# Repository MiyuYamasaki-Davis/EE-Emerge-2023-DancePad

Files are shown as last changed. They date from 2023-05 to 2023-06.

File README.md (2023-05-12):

# Dance Pad Maze Game

[Dance Pad Maze Game](https://github.com/EE-Emerge/EE-Emerge-2023-DancePad) is a game project created by a team of UC Davis [EE-Emerge](https://www.ece.ucdavis.edu/ieee/home/ee-emerge/) (EEC 105ABC) students. This project allows a user to play a game in which they must navigate a maze by using a 4-directional pressure pad controller we built ourselves.

## Table of Contents

1. [About the Project](#about-the-project)
2. [Project Status](#project-status)
3. [Getting Started](#getting-started)
    1. [Dependencies](#dependencies)
    1. [Building](#building)
4. [How to Get Help](#how-to-get-help)
5. [Further Reading](#further-reading)
6. [Authors](#authors)
7. [Acknowledgements](#acknowledgements)

# About the Project

Maze Game, inspired by the popular arcade game Dance Dance Revolution, or commonly abbreviated as DDR, is an interactive game that challenges the user to think on the fly and tests their cognitive capabilities. The basic premise of the game is to navigate randomized mazes with the use of four pressure pads, indicating the direction of which the user can move: forward, back, left and right. The user simply has 30 seconds to complete as many mazes as they can and can compete their skills against other friends and competitors for a spot on the record leaderboard.

# Project Status

Modifications to Pressure Plates
Restructuring of Enclosure
Redesign of PCB

# Getting Started

This repository can be downloaded [here](https://github.com/EE-Emerge/EE-Emerge-2023-DancePad/archive/master.zip), or cloned by:
```
git clone https://github.com/EE-Emerge/EE-Emerge-2023-DancePad
```

## Dependencies

#### Software
[Visual Studio](https://visualstudio.microsoft.com/vs/) was our main program we used to run the game and algorithm.

[Arduino IDE](https://www.arduino.cc/en/software) was used to be able to facilitate communicate between our circuit and the computer.

#### Hardware & Model Creation
[Altium](https://www.altium.com/) was used for most PCB creation.  
[Fusion 360](https://www.autodesk.com/products/fusion-360/overview) was used for the creation of enclosures and other mechanical files.  

## Building

PCB and enclosure files will be located in respective subdirectories. These were fabricated either with a 3D printer, a laser cutter, or table saw.

Software will have to be compiled and loaded into Visual Studio 2022 and Arduino IDE respectively.

# How to Get Help

You can request any changes by making a [pull request](https://github.com/EE-Emerge/EE-Emerge-2023-DancePad/pulls) or opening an issue.

# Further Reading

* [MST Algorithm](https://www.geeksforgeeks.org/kruskals-minimum-spanning-tree-algorithm-greedy-algo-2/)

# Authors

* [Grant Yamaguchi](https://github.com/MiyuYamasaki-Davis)
* [Liana Goldstein](https://)
* [Ricky](https://)
* [RJ](https://)
* [Rameen](https://)
* [Gabe](https://)
* [Cesar Luna](https://)
* [Rayyan](https://)
* [Sean Alling](https://www.ece.ucdavis.edu/blog/alling-sean/)
* [Professor Andre Knoesen](https://faculty.engineering.ucdavis.edu/knoesen/)

# Acknowledgments

Thanks to Texas Instruments for sponsoring EE-Emerge, along with Sean Alling and Dr. Andre Knoesen. We would not have gotten this far without their help and support.

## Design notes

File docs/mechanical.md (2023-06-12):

# Encasement and Mechanical Design

The directional pad encasement is made out of wood and acrylic to minimize cost and create more durability in the frame to allow for all player sizes (children, adults, etc.). The board is was designed in Fusion 360 and custom-made by the team, with areas for wires to go between sections, output to a computer outside the board, and allow for proper compresion of each arrow plate.

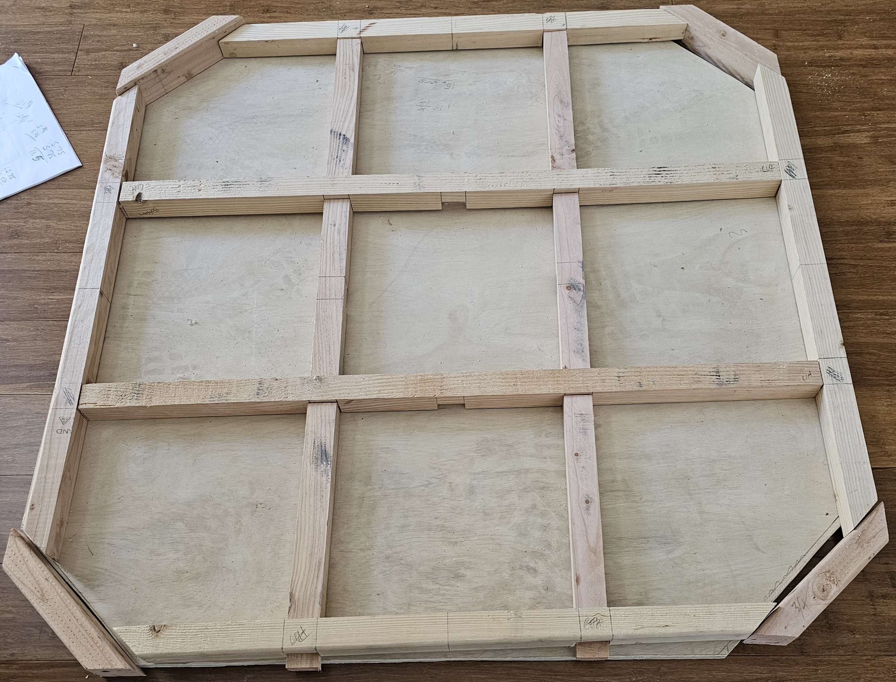
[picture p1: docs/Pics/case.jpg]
Encasement


The PCBs and microcontroller are protected in the center square and receive inputs from each arrow square. Each arrow square contains two wood pieces with copper tape that face each other on opposing sides (top and bottom), which are connected to a designated comparator circuit in our PCB via soldered wires. The two wood pieces are separated by foam pieces placed in corners of the square, preventing contact between the copper tapes when the arrow is unpressed, and creating an open circuit. When the arrow is pressed, the foam compresses and the wood flexes, allowing contact between the copper tapes, changing the circuit from an open circuit to a closed circuit, and signaling to the comparator circuit that an arrow has been pressed.

The system we use in conjunction with the comparator circuit is a pressure plate-like mechanism. 

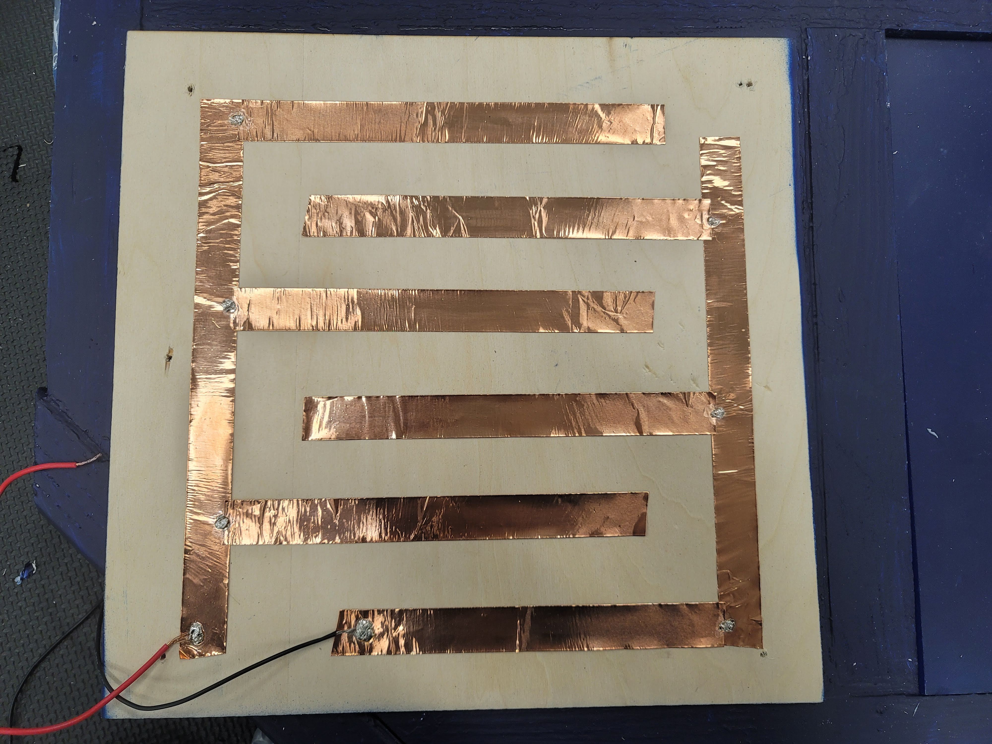
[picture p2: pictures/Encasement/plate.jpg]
Plate Design PHOTO


By layering copper conductive tape and connecting the wires on the bottom plate as shown above, and using no wires and diagonally placed copper tape on the top plate, there is a large area that the player can step on in order to complete the circuit. The top plate tape acts as a jumper between the positive and negative connections of the tape on the bottom plate. This triggers the comparator circuit to allow a voltage through the operational amplifier, creating an analog signal to be converted by the arduino, which then communicates with our C++ game, allowing the user to play.

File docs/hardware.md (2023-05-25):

# Hardware Design

Our PCB's purpose is to compare two voltages. A threshold voltage and the pressure plate voltage. Once the pressure plate is pressed it becomes higher than the threshold. Therefore registering a press on our sensor. We accomplished this by using a comparator circuit.

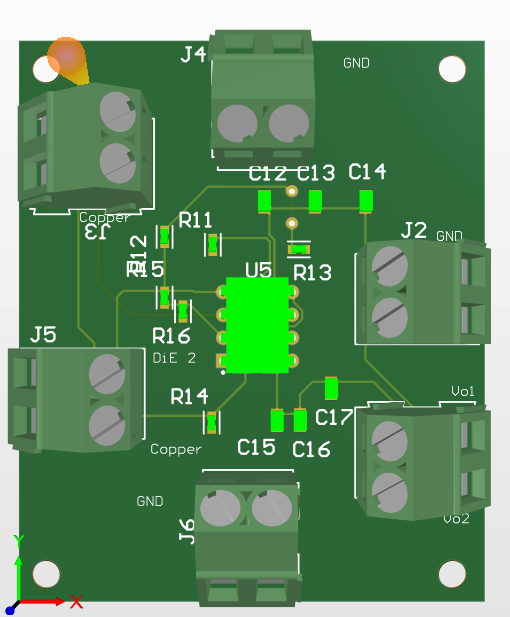
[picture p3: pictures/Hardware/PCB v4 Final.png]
Comparator


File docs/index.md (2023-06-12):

# Pressure Plate Maze Game

[Pressure Plate Maze Game](https://github.com/EE-Emerge/EE-Emerge-2023-DancePad) is a game project created by a team of UC Davis [EE-Emerge](https://www.ece.ucdavis.edu/ieee/home/ee-emerge/) (EEC 105ABC) students. The Maze Game, inspired by the popular arcade game Dance Dance Revolution, is an interactive game that challenges the user to think on the fly and test their cognitive capabilities. The premise of the game is to navigate through randomized mazes using four pressure pads indicating the direction the user will move: forward, back, left and right. The user simply has 30 seconds to complete as many mazes as they can, attempting to beat their friends and competitors and gain a spot on the leaderboard.

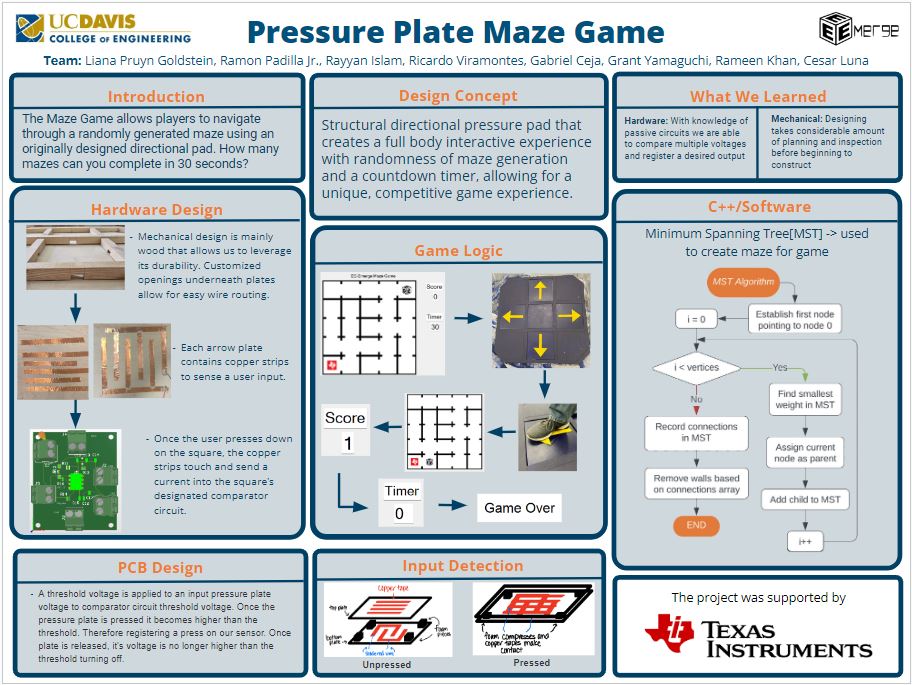
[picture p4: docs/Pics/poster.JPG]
Poster


# About the Project

Pressure Plate Maze Game is a project developed during the 2022/2023 academic year by the undergraduates from EE-Emerge, a project based class at the University of California Davis, designed for students in Computer and Electrical Engineering students to utilize their engineering knowledge and collaborate with others to create a project based on a a yearly theme. In 2022/2023, the students were tasked with creating something to inspire K-12 students and get them interested in Engineering. The Maze Game is an interactive game where the user is challenged to navigate through as many mazes as they can with the use of a 4 direction pressure pad. The user can either move forward, back, left and right and has to complete as many mazes possible in the allocated 30 seconds. At the core of the Maze Game’s technology, inside the middle plate of the pressure pad housing, there are custom PCBs which the team designed and fabricated. The housing has also been designed, laser cut, built, and painted by the team. The PCBs are connected directly with each pad and have a basic function of detecting when the pad is pressed by reading the voltage from our mechanism, which will be either an open or short circuit based on the pressure applied (open when unpressed and short when pressed). The mechanism is connected through the PCBs and microcontroller, where the analog data is looped and debounced, and sent through the serial port to the computer. The randomized mazes and computer game as a whole were created in C++ and utilize minimum spanning trees to generate randomized mazes with a minimum of 3 spaces in between the users starting point and the designated end point.

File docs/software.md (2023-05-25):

# Software Design
The project incorporates a randomly generated maze as the game through an algorithm known as a Minimum Spanning Tree, or MST. This algorithm utilizes randomly assigned weights between neighboring nodes, then runs a procedure to connect the nodes based on the smallest weights found. From this, the program is able to create a tree with dangling child nodes that result in dead ends. This solution also guarantees that a single path from any one point to another will always be feasible, no matter the points chosen.

This project was handled by two software programs: Visual Studio 2022 Community Build and Arduino IDE

## Visual Studio 2022
Visual Studio 2022 is an open source IDE that allows utilization of C++/CLI to develop graphics based C++ projects. It was chosen as the optimal coding environment for C++.

## Arduino IDE
Arduino IDE is the coding source for the Arduino Uno board used to fascilitate Analog-to-Digital Conversion for communication between the PCB and computer.

## Minimium Spanning Tree Algorithm Flowchart
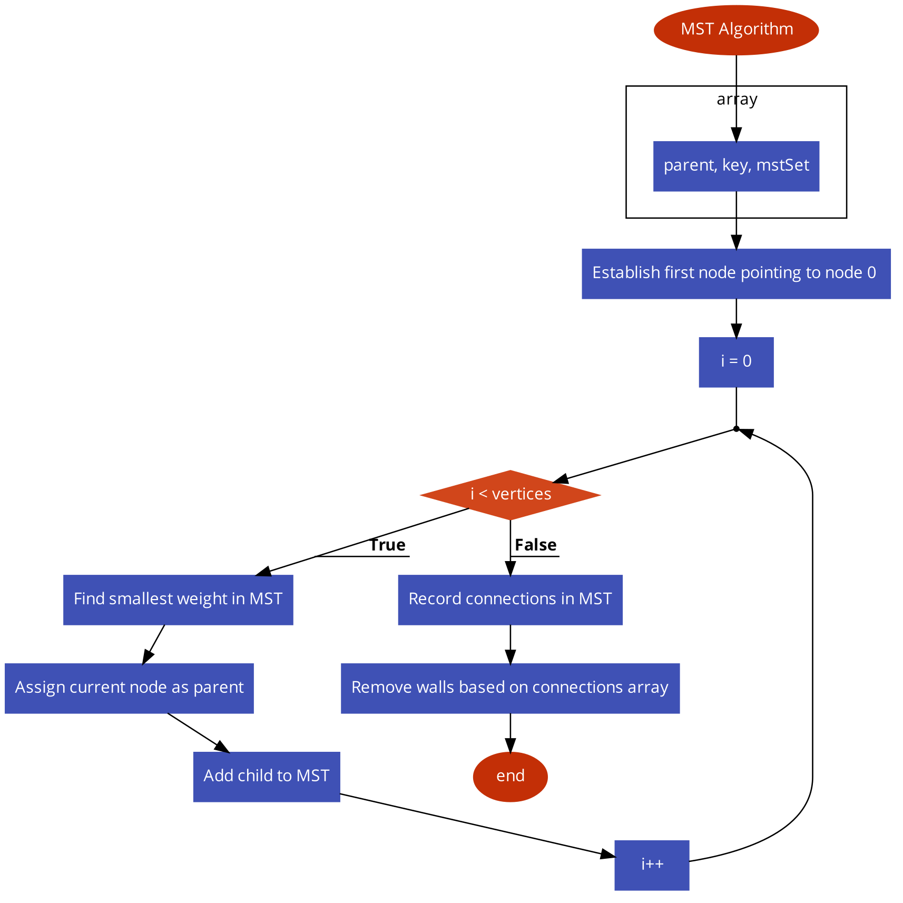
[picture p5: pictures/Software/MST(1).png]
MST


## Timer Loop Flowchart
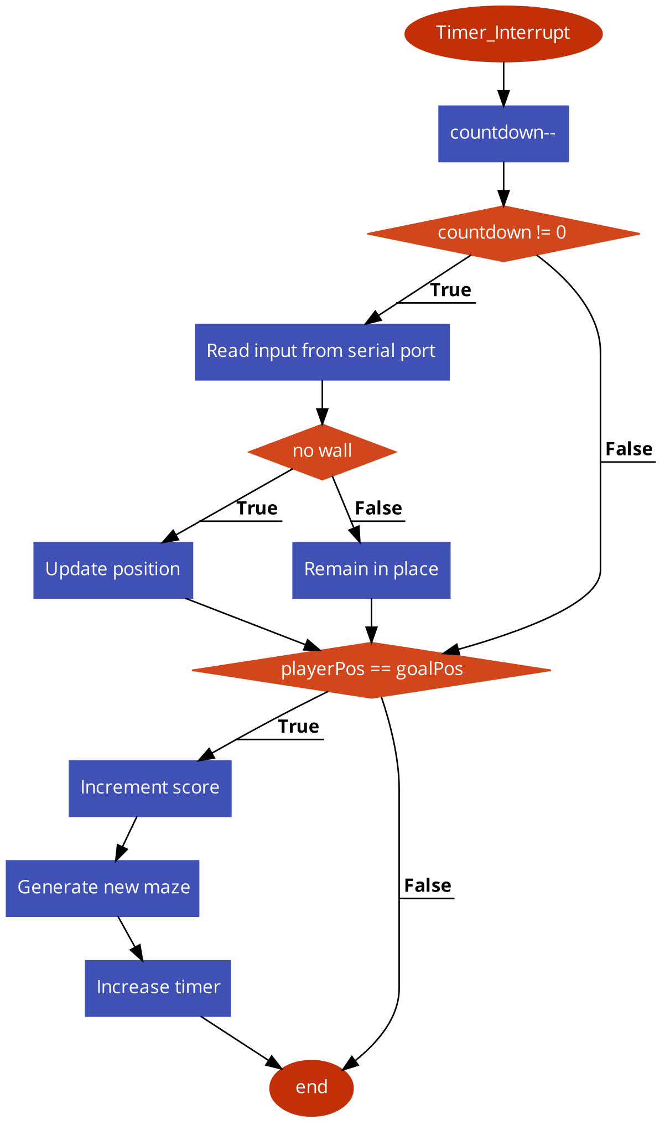
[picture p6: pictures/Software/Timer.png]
Timer


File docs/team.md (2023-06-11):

# Team



| | |
|:---:|:---:|
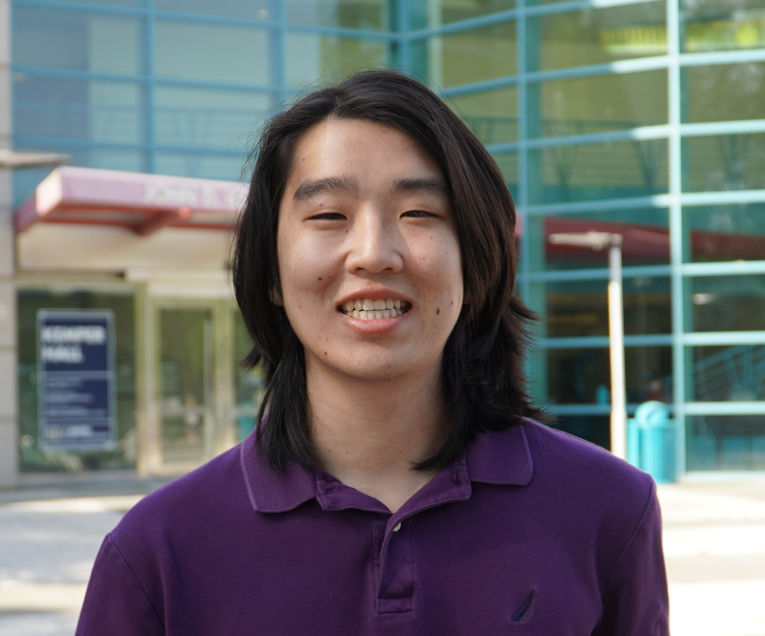
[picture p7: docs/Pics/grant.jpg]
|**Grant Yamaguchi** <br/> **Team Leader / Lead Programmer** <br/> B.S. Computer Engineering 2025 <br/> Major Focus: C++, Python <br/> [LinkedIn](www.linkedin.com/in/grant-j-m-yamaguchi) & [GitHub](https://github.com/MiyuYamasaki-Davis) |  | 
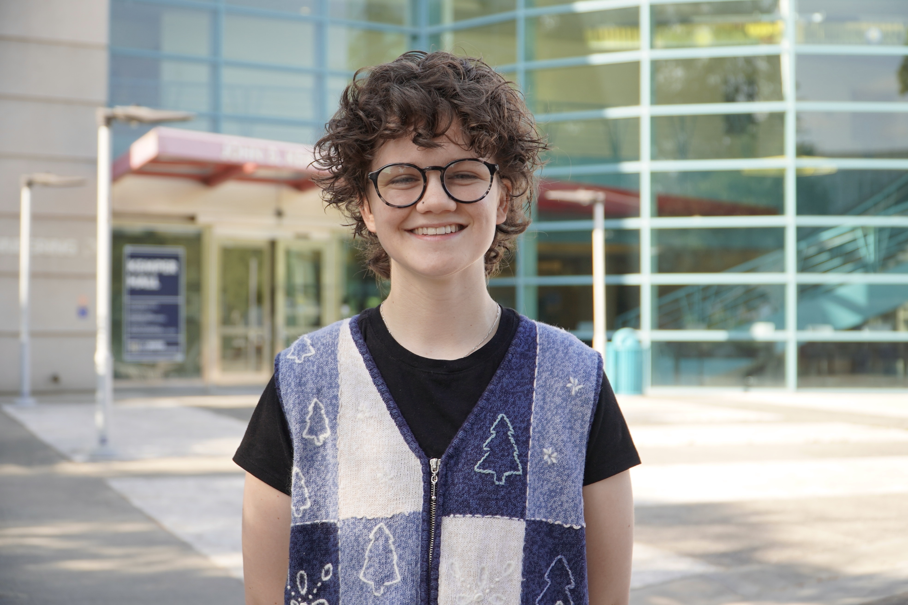
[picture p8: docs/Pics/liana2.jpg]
|**Liana Pruyn Goldstein** <br/> **Team Leader / Various Roles** <br/> B.S. Computer Engineering 2025 <br/> Major Focus: N/A <br/> [LinkedIn](https://www.linkedin.com/in/liana-pruyn-goldstein-94a753207/) |  |
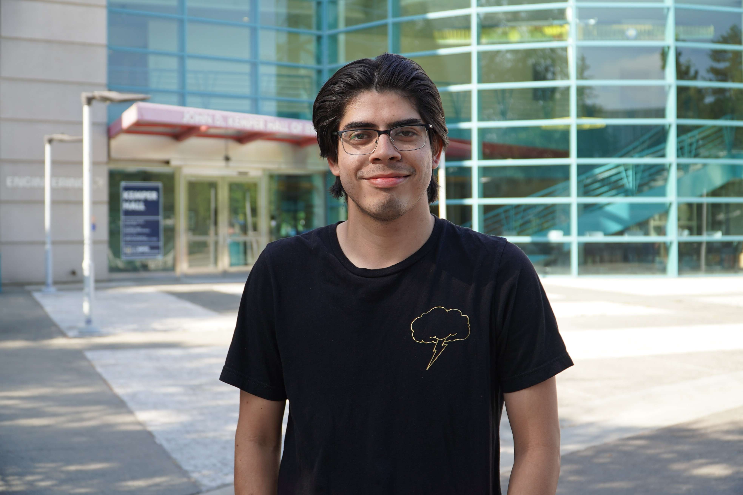
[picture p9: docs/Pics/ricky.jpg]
|**Ricardo Viramontes** <br/> **Hardware Design** <br/> B.S. Electrical Engineering 2024 <br/> Major Focus: RFIC Design <br/> |  |
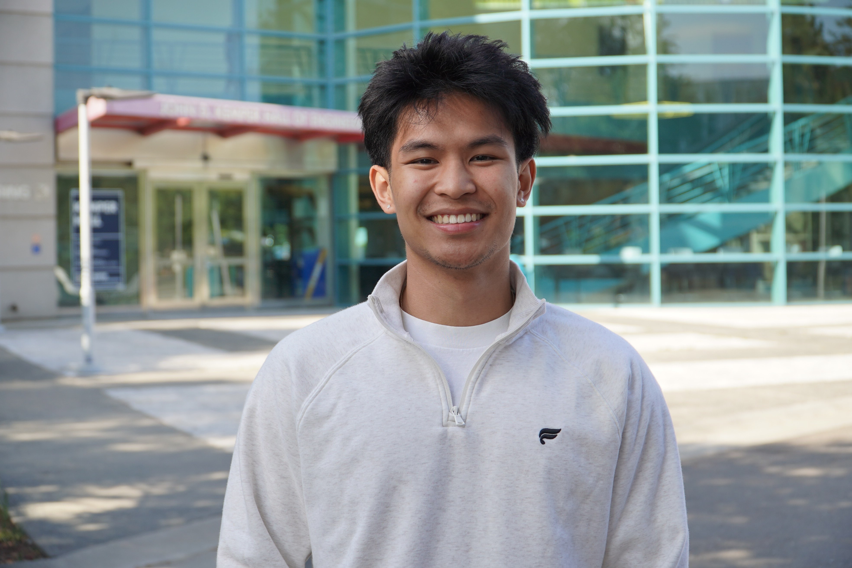
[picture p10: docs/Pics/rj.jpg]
|**Ramon Lamamigo Padilla Jr.** <br/> **Hardware Assembly** <br/> B.S. Electrical Engineering 2024 <br/> Major Focus: RF/Electromagnetics <br/> [LinkedIn](https://www.linkedin.com/in/rj-padilla-9519b3199/) & [GitHub](https://github.com/rjpadilla) |  |
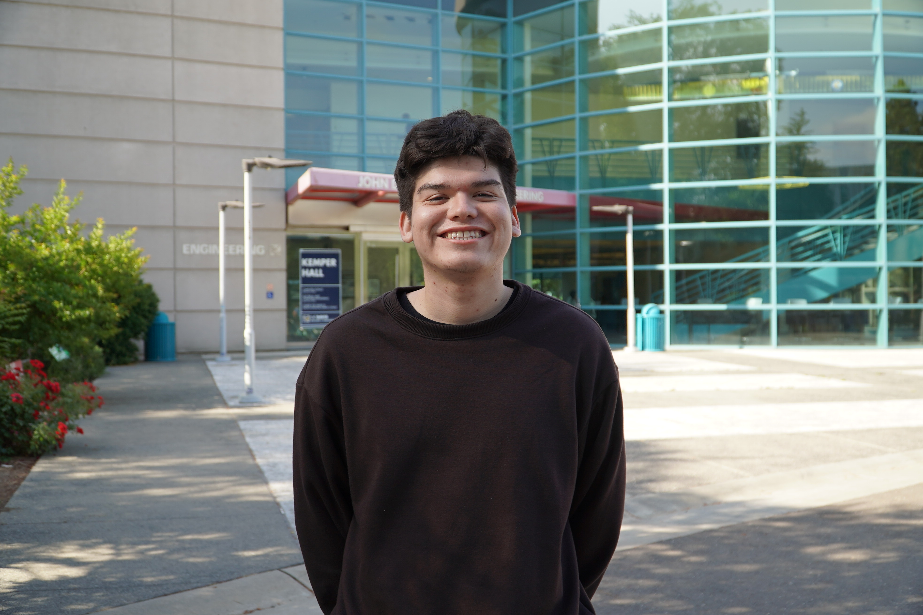
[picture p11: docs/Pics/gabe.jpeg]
|**Gabriel Ceja** <br/> **Encasement & Hardware Design** <br/> B.S. Electrical Engineering 2024 <br/> Major Focus: Analog Design <br/> [LinkedIn](www.linkedin.com/in/gabrielceja) & [GitHub](https://github.com/gabrielceja) |  |
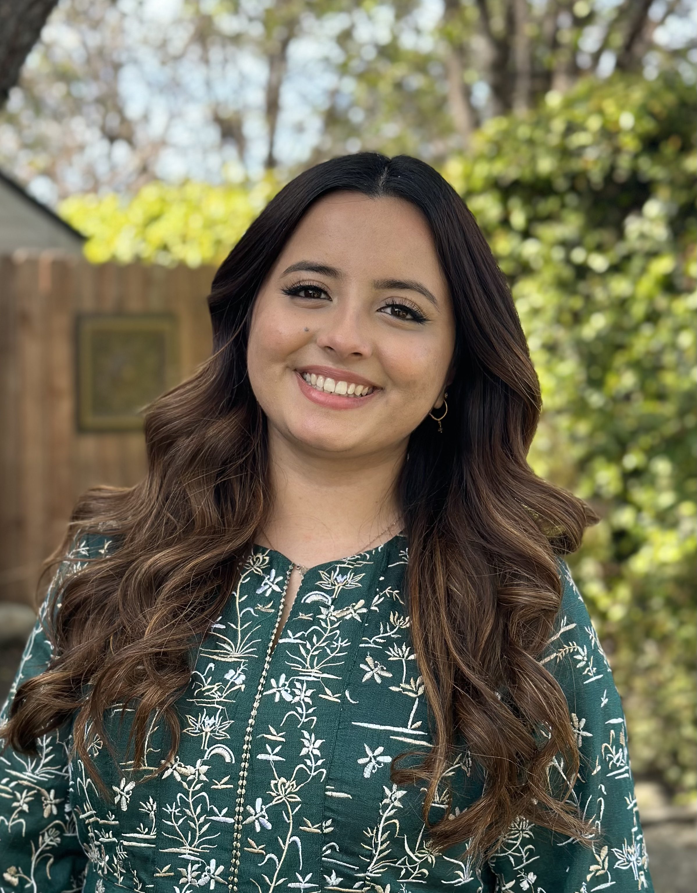
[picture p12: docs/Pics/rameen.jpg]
|**Rameen Khan** <br/> **Encasement & Hardware Design** <br/> B.S. Electrical Engineering 2024 <br/> Major Focus: N/A <br/> [LinkedIn](https://www.linkedin.com/in/rameen-a-khan) & [GitHub](https://github.com/rameeeeenkhan) |  |
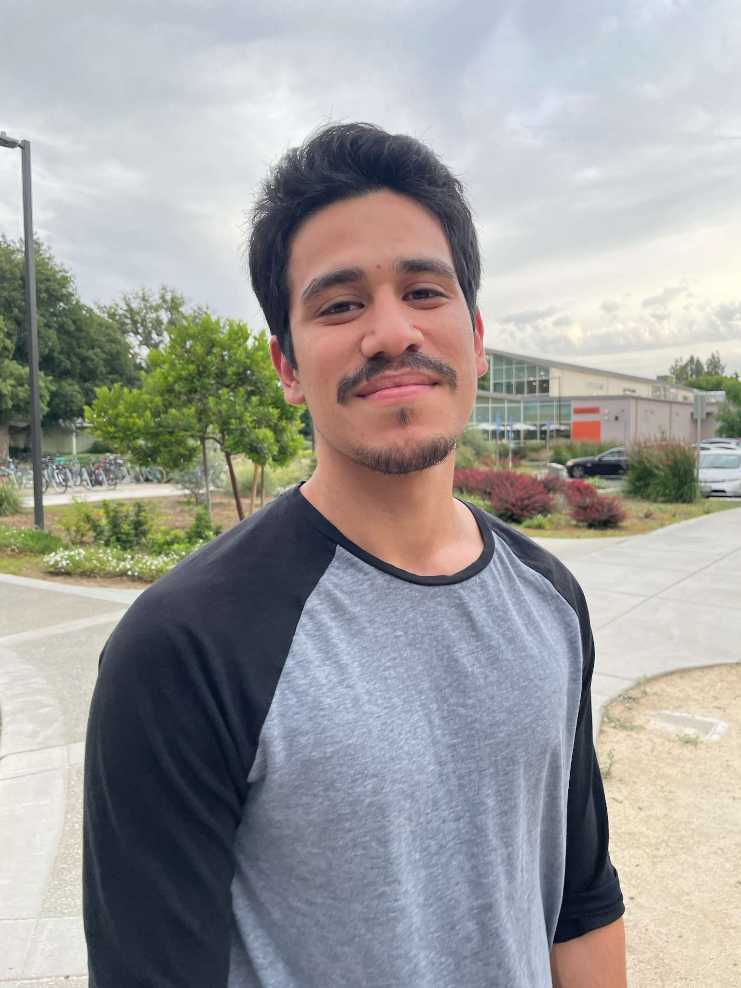
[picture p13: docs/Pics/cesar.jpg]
|**Cesar Luna** <br/> **Various Roles** <br/> B.S. Electrical Engineering 2024 <br/> Major Focus: N/A <br/> [LinkedIn](https://www.linkedin.com/in/cesar-luna-321a45222) & [GitHub](https://github.com/Cesar-A-Luna) |  |
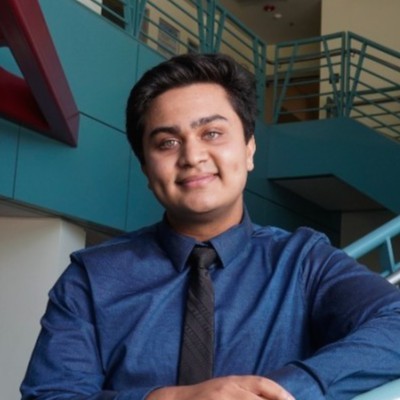
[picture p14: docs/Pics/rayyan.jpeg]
|**Rayyan Islam** <br/> **Various Roles** <br/> B.S. Electrical Engineering 2024 <br/> Major Focus: RF Design <br/> [LinkedIn](https://www.linkedin.com/in/rayyislam/) |  |

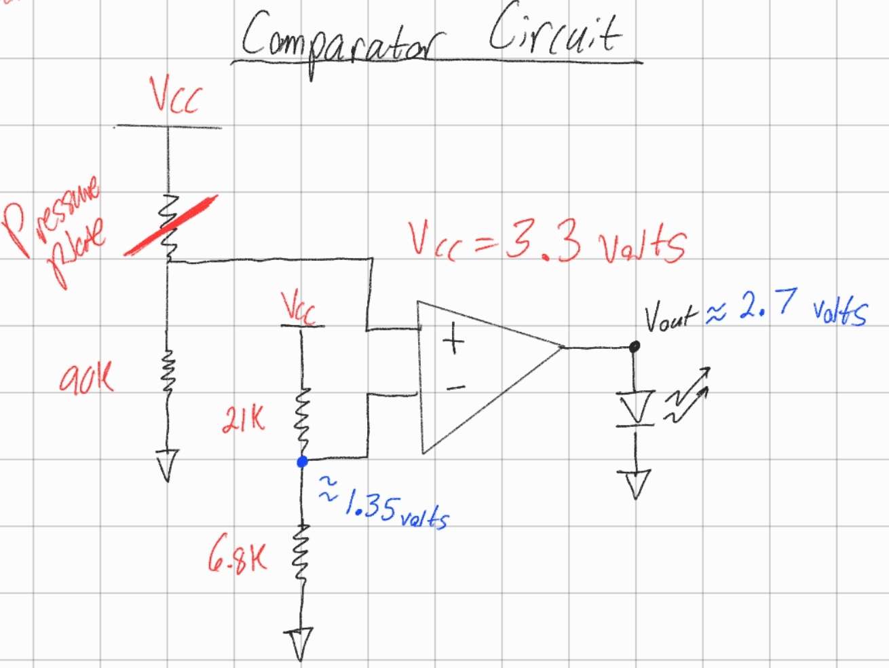
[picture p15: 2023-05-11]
pictures/Hardware/Comparator design.jpg

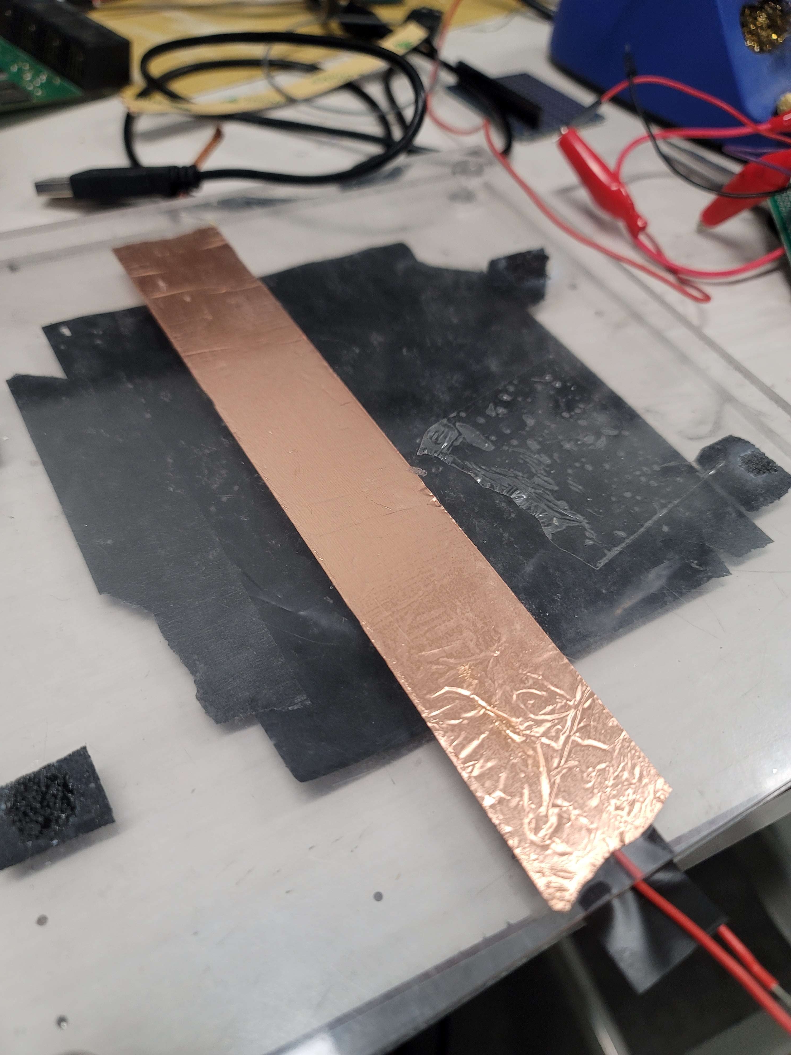
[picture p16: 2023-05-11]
pictures/Encasement/v4 plate design.jpg

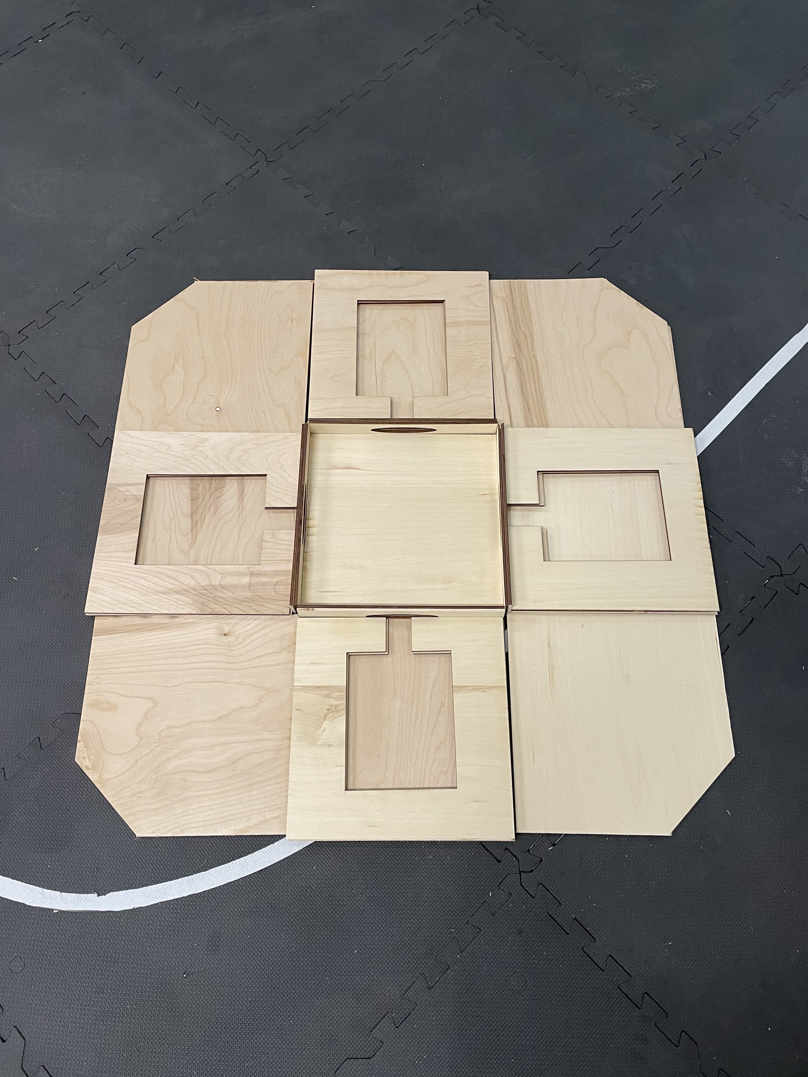
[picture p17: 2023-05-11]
pictures/Encasement/v3 platform design.jpg

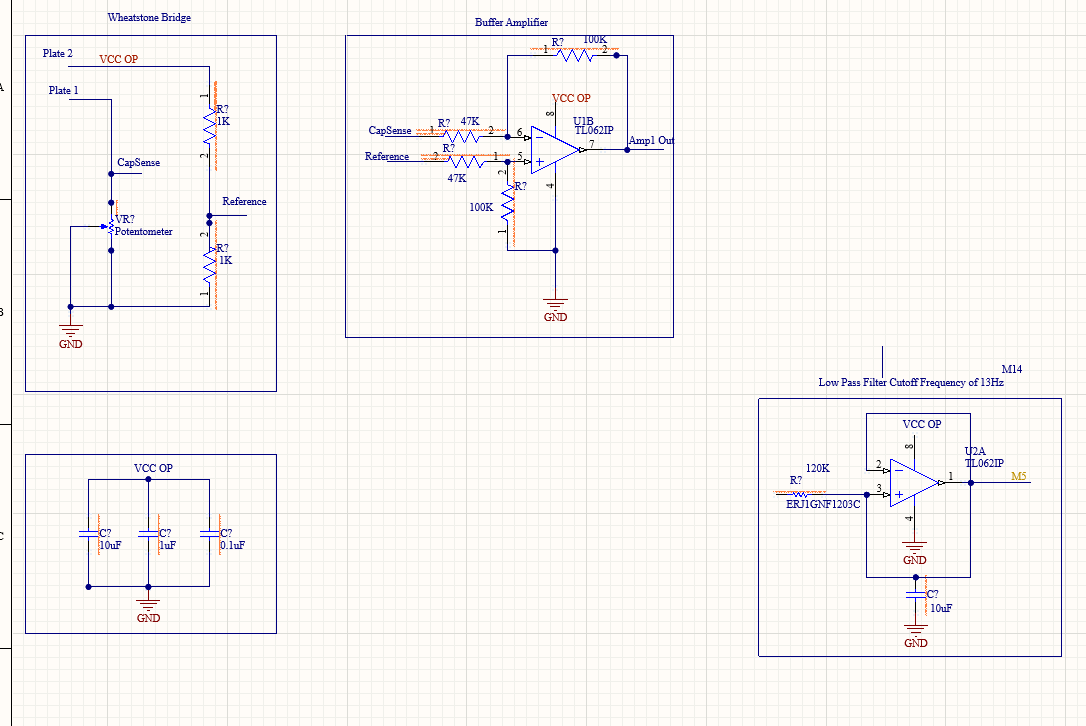
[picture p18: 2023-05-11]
pictures/Hardware/v2 PCB.png

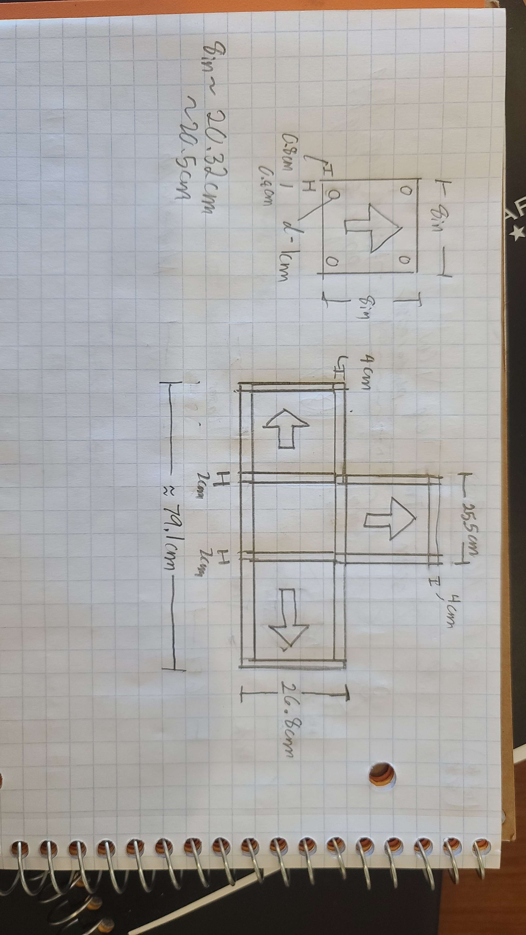
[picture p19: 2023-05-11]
pictures/Encasement/v1 plate design.jpg

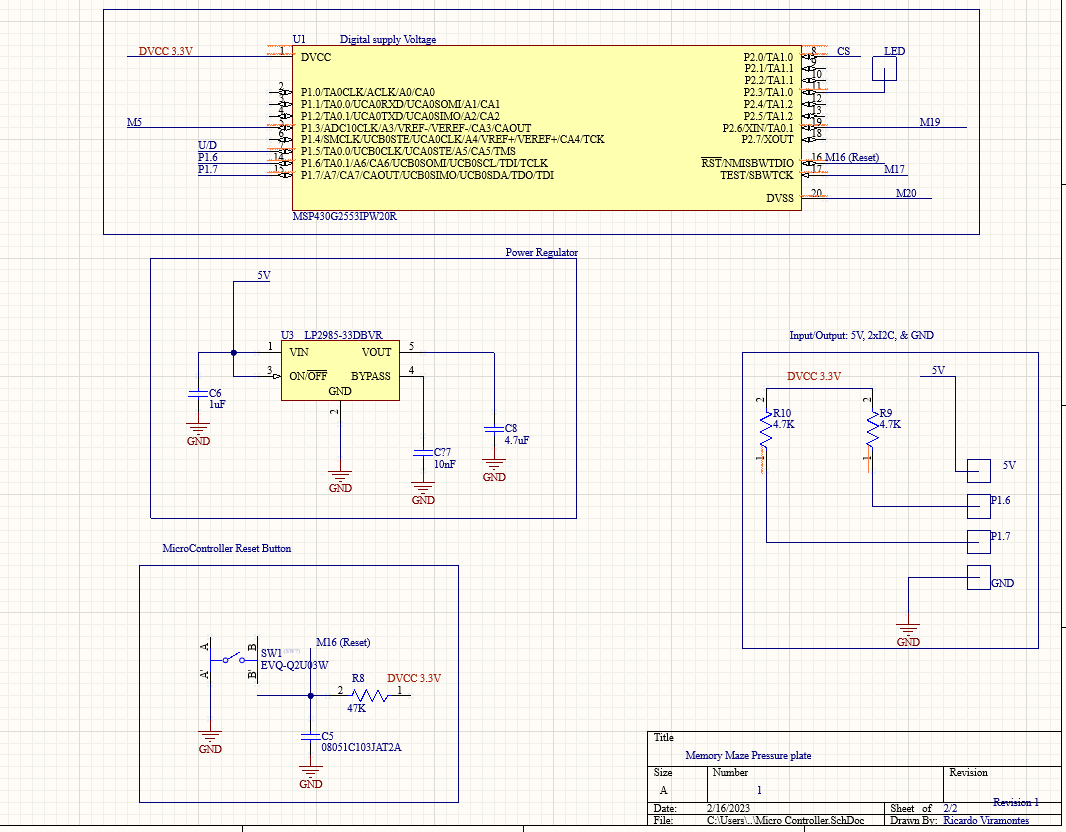
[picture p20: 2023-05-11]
pictures/Hardware/PCB v3 page 2.png

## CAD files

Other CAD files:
pictures/Encasement/v1 plate model.f3d
pictures/Encasement/v2 plate model.f3d

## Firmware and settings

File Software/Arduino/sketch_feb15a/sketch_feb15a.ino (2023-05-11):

// C++ code
//

// include the library code:
#include <LiquidCrystal.h>

// initialize the library by associating any needed LCD interface pin
// with the arduino pin number it is connected to
const int rs = 13, en = 12, d4 = 9, d5 = 8, d6 = 7, d7 = 6;
LiquidCrystal lcd(rs, en, d4, d5, d6, d7);

// pushbutton pin
const int buttonPin1 = A5;
const int buttonPin2 = A4;
const int buttonPin3 = A3;
const int buttonPin4 = A2;

static bool used1, used2, used3, used4;
static int buttonState1, buttonState2, buttonState3, buttonState4; 

void setup()
{
  //pinMode(LED_BUILTIN, OUTPUT);
  // Set up the pushbutton pins to be an input:
  pinMode(buttonPin1, INPUT);
  pinMode(buttonPin2, INPUT);
  pinMode(buttonPin3, INPUT);
  pinMode(buttonPin4, INPUT);

  used1 = false;
  used2 = false;
  used3 = false;
  used4 = false;
  
  // set up the LCD's number of columns and rows:
  lcd.begin(16, 2);
  // Print a message to the LCD.
  lcd.print("hello, press a");
  lcd.setCursor(0,2);
  lcd.print("button to start\n");

  Serial.begin(9600);
}

void loop()
{
  // local variable to hold the pushbutton states
  buttonState1 = analogRead(A5);
  delay(15);
  buttonState1 = analogRead(A5);
  delay(30);
  buttonState2 = analogRead(A4);
  delay(15);
  buttonState2 = analogRead(A4);
  delay(30);
  buttonState3 = analogRead(A3);
  delay(15);
  buttonState3 = analogRead(A3);
  delay(30);
  buttonState4 = analogRead(A2);
  delay(15);
  buttonState4 = analogRead(A2);
  delay(30);

  if (buttonState1 > 300 && !used1) {
    used1 = true;
    Serial.print("R");
    //Serial.println(buttonState1 * 5.0 / 1024.0);
    delay(50);
  }
  else if (buttonState1 < 50) {
    used1 = false;
    delay(10);
  }
  if (buttonState2 > 300 && !used2) {
    used2 = true;
    Serial.print("U");
    //Serial.println(buttonState2 * 5.0 / 1024.0);
    delay(50);
  } 
  else if (buttonState2 < 50) {
    used2 = false;
    delay(10);
  }
  if (buttonState3 > 300 && !used3) {
    used3 = true;
    Serial.print("L");
    //Serial.println(buttonState3 * 5.0 / 1024.0);
    delay(50);
  } 
  else if (buttonState3 < 50) {
    used3 = false;
    delay(10);
  }
  if (buttonState4 > 300 && !used4) {
    used4 = true;
    Serial.print("D");
    //Serial.println(buttonState4 * 5.0 / 1024.0);
    delay(50);
  } 
  else if (buttonState4 < 50) {
    used4 = false;
    delay(10);
  }
}
